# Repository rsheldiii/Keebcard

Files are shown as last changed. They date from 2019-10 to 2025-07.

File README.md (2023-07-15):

# The KeebCard, an open-source, low-power, mechanical switch computer keychain

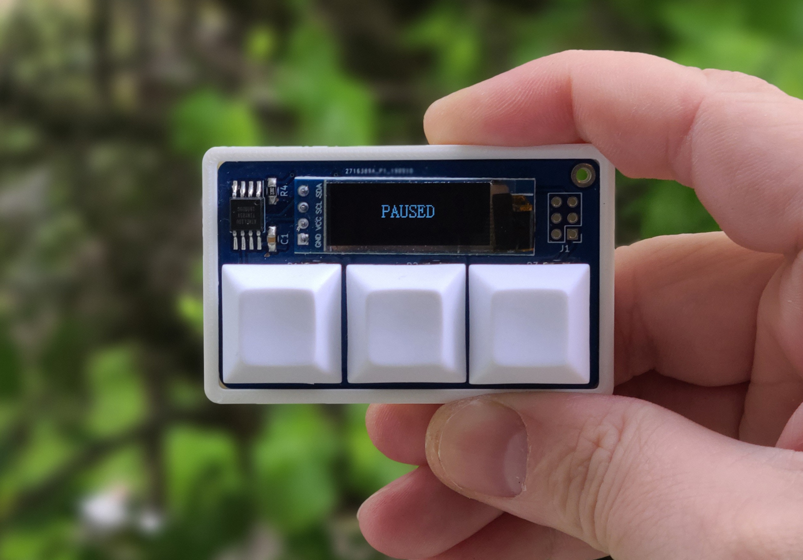
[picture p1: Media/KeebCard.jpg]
Prototype KeebCard picture


This is the home of the KeebCard project. Originally designed as a business card, people loved it so much I decided to release a version of it as open-source (TODO: add a license).

The KeebCard is centered around an SSD1306-powered 128x32 monochromatic display and an ATTINY85-10SU. The code uses the wonderful [Tiny4kOLED library](https://github.com/datacute/Tiny4kOLED) to communicate with the screen via i2c. With 8 kilobytes of program space and 512 bytes of RAM, it's a fun challenge getting anything to run on this thing!

# OpenSaucers

OpenSauce attendees, thanks for supporting TheKeebProject! Check out the DIY assembly video below. The amount of components present in the bag indicates what they are; there is one capacitor, two i2c resistors (on the back) and four pull-up resistors. The assembly video should go over everything, if you have any trouble get in touch!

## DIY Assembly

[Head here for the current DIY assembly video](https://www.youtube.com/watch?v=mJQla--lSXY).

## Case Assembly (Button and LowPro)

Watch [this quick video](https://www.youtube.com/watch?v=yVERQCmgONw) if you want to know how to use the cases! Especially important for button cases, they can be tricky

# Flashing/Code

At the base of this project (currently) is the code that runs on the machine, you can `git clone` or download zip and open the KeebCard.ino file in Arduino. I don't normally program in C++, so it's a little rough. You can change what program is flashed by changing the define at the top of KeebCard.ino.

The KeebCard code is currently compiled and flashed with an ISP programmer via the Arduino suite. [check out the flashing tutorial here](https://www.youtube.com/watch?v=2kj1aFIwNek)

### A note about dependencies

Currently, all dependencies can be installed via the Arduino library manager, check out the flashing tutorial.

There used to be a dependency on the [Arduino Entropy Library](https://github.com/pmjdebruijn/Arduino-Entropy-Library) that needed to be downloaded separately, but it was causing memory errors due to how the Arduino suite includes files. I'll be breaking programs out into separate folders eventually, after which we'll reinstate the entropy library.

# Flashing your own programs

I made a guide on how Conway's Game of Life works on the KeebCard, which will hopefully help you write your own programs! you can check that out [here](https://www.youtube.com/watch?v=X3y9NNHXf2Y)

# Troubleshooting

Having successfully hand-soldered >30 of these now, I put the two most common problems people encounter in [this video](https://www.youtube.com/watch?v=W7IxT4Zf5qs). If you're having issues take a look!

# Fabbing

If you want to make your own run of KeebCard boards, check out the GERBERS directory. These are gerbers produced by the standard settings in Kicad. They are confirmed to work with JLCPCB, but probably work just fine at a bunch of other board shops.

## BOM

All parts are available from Mouser save the screen

* 1x [SMTU2032-LF](https://www.mouser.com/ProductDetail/614-SMTU2032-LF)
* 1x [0805 0.1uF capacitor](https://www.mouser.com/ProductDetail/710-885012207016)
* 4x [0805 22kOhm resistors](https://www.mouser.com/ProductDetail/603-RC0805FR-0722KL)
* 2x [0805 4.7 kOhm resistors](https://www.mouser.com/ProductDetail/603-RC0805FR-074K7L)
* 1x [ATTINY85V-10SU](https://www.mouser.com/ProductDetail/556-ATTINY85V10SU)
* [Some headers](https://www.mouser.com/ProductDetail/538-22-28-4012)
* 1x [screen](https://www.aliexpress.com/item/32712441521.html?spm=a2g0s.9042311.0.0.296f4c4dcIoeUh)
* 3x [cherry MX](https://www.mouser.com/ProductDetail/CHERRY/MX1A-E1NW) or Kailh Choc switches and keycaps

# Modifying

If you want to modify the design, check out the KeebCard directory, which houses the original Kicad project.  

# KeebCard in media

If you've seen the KeebCard elsewhere, please let me know!

* Unilad Tech: https://www.facebook.com/UNILADTech/videos/1574779679325114/?v=1574779679325114
* AlexGyver's Youtube channel: https://www.youtube.com/watch?v=djgHV5JCNTk

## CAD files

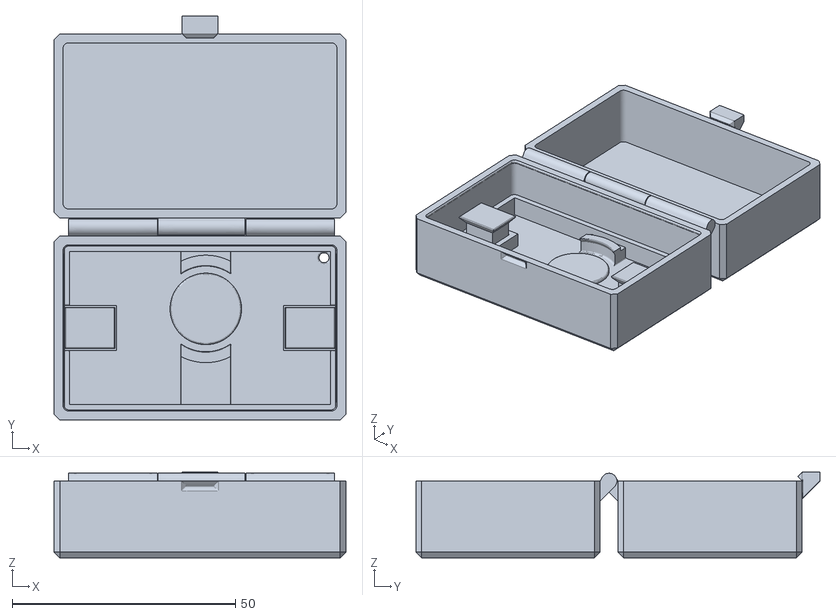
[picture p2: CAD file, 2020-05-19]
Cases/KeebCard Battery Case v18.stl
65.3 x 90.4 x 19.2

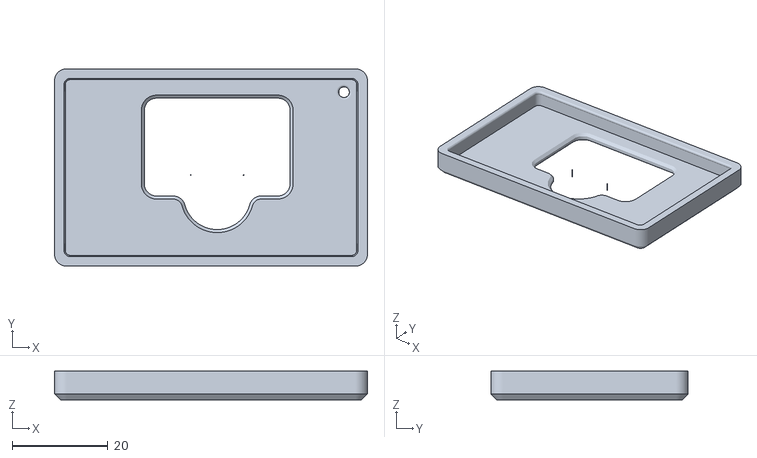
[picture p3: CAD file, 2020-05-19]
Cases/KeebCard LowPro Case v2.stl
65.3 x 41.2 x 6.05

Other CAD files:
Cases/KeebCard Battery Case v18.f3d
Cases/KeebCard LowPro Case v3.f3d

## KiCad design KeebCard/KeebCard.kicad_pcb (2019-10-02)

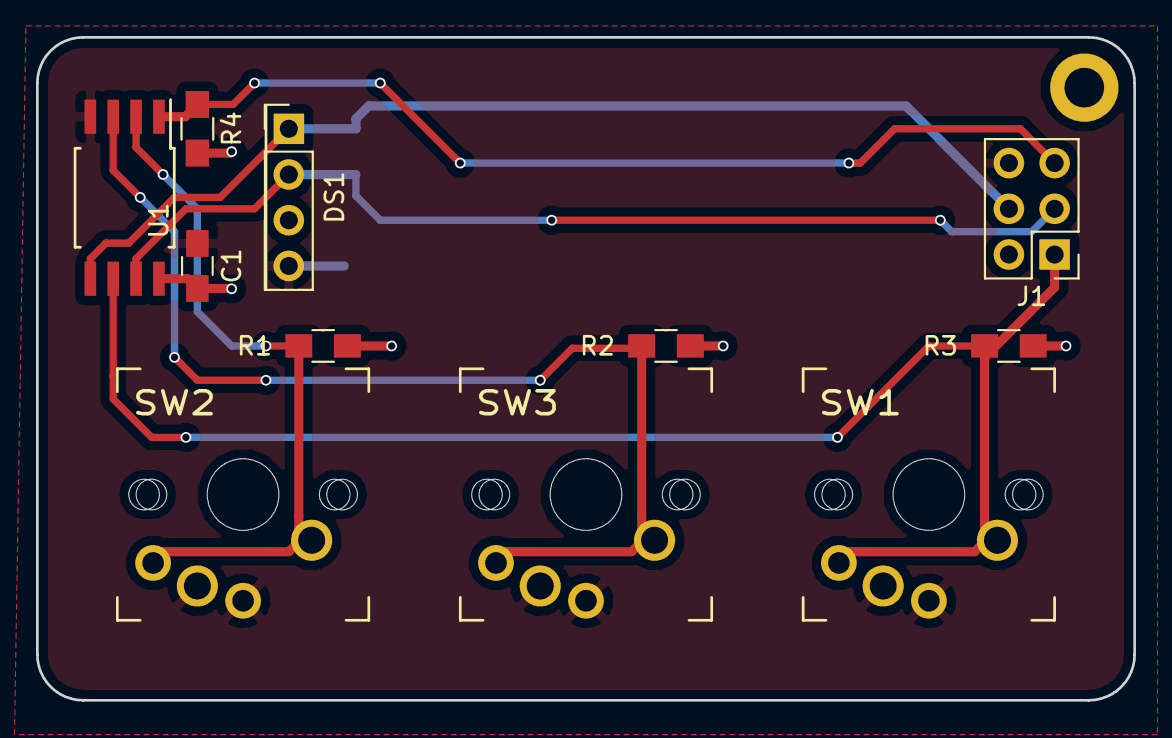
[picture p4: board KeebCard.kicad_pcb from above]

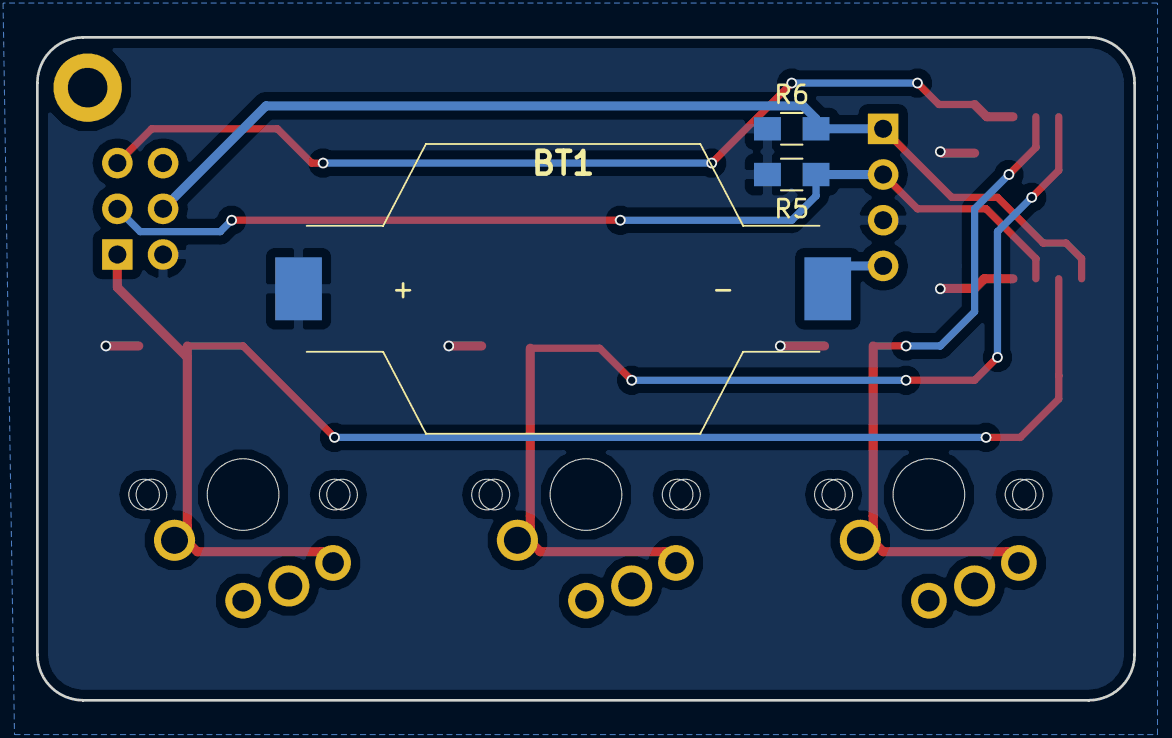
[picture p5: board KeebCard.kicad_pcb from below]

Board: 2 copper layers, 61.0 x 36.8 mm, 14 parts (3 on the bottom side), 8 nets.

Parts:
BT1: CR2032; SMTU2032
C1: 100nF; C_0805_HandSoldering
DS1: SSD1306-128x32; SSD1306_OLED_Display_128x32
J1: Conn_02x03_Odd_Even; Pin_Header_Straight_2x03_Pitch2.54mm
R1, R2, R3, R4: 22K; R_0805_HandSoldering
R5, R6: 4.7k; R_0805_HandSoldering
SW1, SW2, SW3: SW_Push; CHERRY_CHOC_PCB
U1: ATTINY85-20SU

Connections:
/PB0: DS1.4, J1.4, R6.1, U1.5
/PB1: J1.1, R3.2, SW1.2, U1.6
/PB2: DS1.3, J1.3, R5.1, U1.7
/PB3: R1.2, SW2.2, U1.2
/PB4: R2.2, SW3.2, U1.3
/PB5: J1.5, R4.1, U1.1
GND: BT1.2, C1.2, DS1.1, J1.6, SW1.1, SW2.1, SW3.1, U1.4
VCC: BT1.1, C1.1, DS1.2, J1.2, R1.1, R2.1, R3.1, R4.2, R5.2, R6.2, U1.8

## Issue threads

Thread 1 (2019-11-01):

Some Kicad library are missing

BenRoe, 2019-11-01:
I will add a on/off switch to the pcb.
Problem is that some symbol libraries are missing (bobness_card.lib and KeebCard.lib).
Also the footprints are in six different libraries. Can you move the parts in one symbol and one footprint library?
Or please zip all libraries and upload it. I can merge if you wan't.
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

rsheldiii, 2020-01-22:
Whoops, totally missed this, sorry about that.

None of those libraries are used, so they are safe to ignore. I've removed them from the library tables so this should be all set.

thanks for pointing this out!

Closed 2020-01-22.

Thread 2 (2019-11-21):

Oled flashing pausing continuously

0xhjohnson, 2019-11-21:
Just finished soldering the device up and it is continuously alternating between paused and then plays a frame. Any ideas where to start troubleshooting?

rsheldiii, 2019-11-21:
The screen pausing continuously indicates the voltage on the middle button's GPIO is low - most likely there's a bridge somewhere to ground or another pin. The most common place for that is the microcontroller, so I'd check to make sure there aren't any bridges there. The middle button pin is PB4, which is the second pin from the left on the topmost row of pins when it's on the board. The pin to the left is ground, so any solder bridge to that pin would definitely do it.

Let me know if that's the culprit!

0xhjohnson, 2019-11-22:
Thanks for your help. I will investigate and report back.

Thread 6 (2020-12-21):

Conflicting declaration

MyNameIs-Nigel, 2020-12-21:
Hey! I was following your flashing tutorial on YouTube and found an issue that I am having. I can not compile the code because of an exit. "conflicting declaration 'typedef struct UPosition UPosition'"

How do you think I could go about resolving this issue? Here are the steps I followed to ensure you can run into this error:

1. Download the code from the github
2. Download arduino, rename the keebcard-master to keebcard
3. Open Keebcard.ino
4. Add TinyWireM.h and Tiny4kOLED.h libraries
5. Comment `#define TETRIS` and uncomment `#define PONG`
Compile the code.

These are the exact steps shown in the video (to my memory) and resulted in the following error: (Info and such included in the error message)

```
Arduino: 1.8.9 (Windows 10), Board: "ATtiny25/45/85, ATtiny85, Internal 1 MHz"

In file included from C:\Users\Nigel\Desktop\keebcard\Keebcard.ino:21:0:

Tetris.h:13:3: error: conflicting declaration 'typedef struct Position Position'

 } Position;

   ^

In file included from C:\Users\Nigel\Desktop\keebcard\Conway.cpp:2:0:

sketch\Conway.h:12:3: note: previous declaration as 'typedef struct Position Position'

 } Position;

   ^

exit status 1
conflicting declaration 'typedef struct Position Position'

This report would have more information with
"Show verbose output during compilation"
option enabled in File -> Preferences.
```

MyNameIs-Nigel, 2020-12-21:
Heyy! I just noticed I posted the Wrong error code! My bad!! Still, similar enough error. This error occurs on every one I have found.

Here is the updated error.

```
Arduino: 1.8.9 (Windows 10), Board: "ATtiny25/45/85, ATtiny85, Internal 1 MHz"

In file included from C:\Users\Nigel\Desktop\keebcard\Keebcard.ino:25:0:

Pong.h:7:3: error: conflicting declaration 'typedef struct UPosition UPosition'

 } UPosition;

   ^

In file included from C:\Users\Nigel\Desktop\keebcard\Conway.cpp:2:0:

sketch\Conway.h:7:3: note: previous declaration as 'typedef struct UPosition UPosition'

 } UPosition;

   ^

In file included from C:\Users\Nigel\Desktop\keebcard\Keebcard.ino:25:0:

Pong.h:12:3: error: conflicting declaration 'typedef struct Position Position'

 } Position;

   ^

In file included from C:\Users\Nigel\Desktop\keebcard\Conway.cpp:2:0:

sketch\Conway.h:12:3: note: previous declaration as 'typedef struct Position Position'

 } Position;

   ^

exit status 1
conflicting declaration 'typedef struct UPosition UPosition'

This report would have more information with
"Show verbose output during compilation"
option enabled in File -> Preferences.

```

MyNameIs-Nigel, 2020-12-21:
Hey there! I deleted everything except the necessary files and pong. So this leaves `Keebcard`, `Pong.cpp`, `Pong.h`, and `settings.h`.

Now it will compile.

Still not sure, is this a necessary step? As to my knowledge, you do not include this step in your video..

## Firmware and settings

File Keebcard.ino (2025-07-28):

#include <TinyWireM.h>
#include <Tiny4kOLED.h>
#include <avr/wdt.h>
// #include <Entropy.h>
#include "settings.h"


// PROGRAM DEFINES =============================================================

// uncomment whichever one you want
// #define BUSINESS_CARD
#define TETRIS
// #define CONWAY
// #define PONG
// #define SNAKE

// cut down on features since digispark has a big bootloader
// #define DIGISPARK


#ifdef TETRIS
#include "Tetris.h"
#elif defined(CONWAY)
#include "Conway.h"
#elif defined(PONG)
#include "Pong.h"
#elif defined(BUSINESS_CARD)
#include "BusinessCard.h"
#elif defined(SNAKE)
#include "Snake.h"
#endif

void universal_setup() {

  // flip screen horizontally
  // oled.setSegmentRemap(0xA0);
  // flip screen vertically
  // oled.setComOutputDirection(0xC0);

  oled.begin();

  oled.setFont(FONT8X16);
  // Switch the half of RAM that we are writing to, to be the half that is non currently displayed
  oled.switchRenderFrame();

  // clear both buffers of any dead squirrels
  oled.clear();
  oled.switchFrame();
  oled.clear();

  // Turn on the display
  oled.on();

  // seed random number with value from the analog pin
  // it doesn't vary all that much, but it helps
  // srand(analogRead(MIDDLE_BUTTON) + analogRead(2) + analogRead(3));
  // here's the good stuff, Entropy based off clock jitter
//  Entropy.initialize();

  pinMode(LEFT_BUTTON, INPUT);
  pinMode(RIGHT_BUTTON, INPUT);
  pinMode(MIDDLE_BUTTON, INPUT);

#ifdef SNAKE
  oled.setMemoryAddressingMode(0); // TODO prolly don't need this
  // no double buffering for now. very little to update so it runs fast anyways
  oled.switchRenderFrame();
#endif
}

void wdt_check_reset() {
  MCUSR &= ~(1 << WDRF);  // Clear watchdog reset flag
  wdt_disable();          // Disable watchdog on startup
}


void setup() {
  wdt_check_reset(); // Disable watchdog timer on startup
  universal_setup();
  setup_game();
}

void setup_game() {
#ifdef TETRIS
  GIMSK = 0b00100000;    // turns on pin change interrupts
  PCMSK = 0b00011010;    // turn on interrupts on pins PB0, PB1, &amp;amp; PB4
  sei();                 // enables interrupts

  Tetris tetris(&oled);
  gameOver(tetris.run());
  oled.switchFrame();
#elif defined(CONWAY)
  oled.setMemoryAddressingMode(0); // TODO prolly don't need this
  Conway conway(&oled);
  conway.run();
#elif defined(BUSINESS_CARD)
  businessCard(&oled);
#elif defined(PONG)
  oled.setCursor(8, 1);
  oled.print(F("PLAYER 1 START"));
  oled.switchFrame();
  delay(800);
  oled.switchFrame();
  oled.clear();
  oled.setMemoryAddressingMode(1);
  Pong pong(&oled);
  pong.run();
#elif defined(SNAKE)
  oled.setCursor(8, 1);
  oled.print(F("NOKIA OS"));
  // oled.switchFrame();
  delay(800);
  // oled.switchFrame();
  oled.clear();
  Snake snake(&oled);
  gameOver(snake.run());
#endif
}

void loop() {
  if (digitalRead(MIDDLE_BUTTON) == LOW) {
    // oled.clear();
    // oled.switchFrame();
    // oled.clear();
    // setup_game();
  }
}

void gameOver(uint32_t score) {
  oled.clear();
  oled.setCursor(0, 0);
  oled.print(F("Game Over!"));
  oled.setCursor(0, 2);
  oled.print(F("Score: "));
  oled.print(score);
  oled.switchFrame();

  delay(100);
  
  // Wait for middle button press to restart
  while (true) {
    if (digitalRead(MIDDLE_BUTTON) == LOW) {
      // Wait for button release to avoid immediate re-trigger
      while (digitalRead(MIDDLE_BUTTON) == LOW) {
          delay(10);
      }

      oled.clear();
      oled.setCursor(0,0);
      oled.print(F("Restarting..."));
      oled.switchFrame();

      delay(100);
      // Enable watchdog timer and reset system
      wdt_enable(WDTO_250MS);
      while(1); // Wait for watchdog reset
    }
    delay(10); // Small delay to prevent excessive CPU usage
  }
}

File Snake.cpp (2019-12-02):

#include "settings.h"
#include "Snake.h"


const uint8_t BOARD_WIDTH = 48;
const uint8_t BOARD_HEIGHT = 16;
const uint8_t STARTING_SCORE = 4;

// the board is not a multiple of the screen height, so this is the difference
// from one edge of the screen to the board
const uint8_t HORIZONTAL_GAP = ((64 - BOARD_WIDTH) / 2);

// if you're reading this and it's still broken out it's for testing purposes
// each byte represents a 16x2 swath of pixels, which is then of course 8 positions 2x2.
// swaths start in the top left and proceed rightwards in rows
// pixels start at the top as well and go downwards
// 8 for uint8_t
const uint8_t BOARD_SIZE = BOARD_WIDTH * BOARD_HEIGHT / 8;


// divided by 4 because quadruple direction
static QuadrupleDirection SnakePath::snakePath[BOARD_WIDTH * BOARD_HEIGHT / 4] = { { RIGHT, RIGHT, RIGHT, RIGHT }, { RIGHT, RIGHT, RIGHT, RIGHT }, { RIGHT, RIGHT, RIGHT, RIGHT } }; // TODO NEEDS TO BE 256(ish) but memory instability

Direction SnakePath::get(uint16_t index) {
  QuadrupleDirection d = snakePath[index >> 2];
  switch((uint8_t)(index & 0b11)) {
    case 0:
      return d.firstDirection;
    case 1:
      return d.secondDirection;
    case 2:
      return d.thirdDirection;
    case 3:
      return d.fourthDirection;
  }
}

void SnakePath::set(uint16_t index, Direction direction) {
  switch((uint8_t)(index & 0b11)) {
    case 0:
      snakePath[index >> 2].firstDirection = direction;
      break;
    case 1:
      snakePath[index >> 2].secondDirection = direction;
      break;
    case 2:
      snakePath[index >> 2].thirdDirection = direction;
      break;
    case 3:
      snakePath[index >> 2].fourthDirection = direction;
      break;
  }
}

static uint8_t Snake::board[BOARD_SIZE] = { 0 };

static Position Snake::tailPosition = {1, 7};
static Position Snake::headPosition = {1 + STARTING_SCORE + 1, 7};
static Position Snake::foodPosition = {32, 7};

static Direction Snake::direction = RIGHT;
static Direction Snake::lastDirection = RIGHT;

static uint16_t Snake::score = STARTING_SCORE;
static bool Snake::gameOver = false;
static bool Snake::scoredThisTurn = false;
static uint8_t Snake::time;
static uint8_t Snake::debounce = 0;
static uint8_t Snake::linksToAdd = 0;

// snakePath defines the association between snake links. Snake links can only be the cardinal neighbor of their next-of-kin, so we only need 4 bits to represent this

Snake::Snake(SSD1306Device* _oled) {
  oled = _oled;
  oled->fill(0);
}

// set up the play area. used at start and for pause
void Snake::setup() {
  oled->setMemoryAddressingMode(1);
  // * 2 because we are rasterized - every pixel is a 2x2 squares
  oled->setCursor((HORIZONTAL_GAP - 1) * 2,0);
  oled->startData();
  for(uint8_t j = 0; j < 8; j++){
    oled->sendData(0xffff);
  }

  oled->endData();
  oled->setCursor((BOARD_WIDTH + HORIZONTAL_GAP) * 2, 0);
  for(uint8_t i = 0; i < 8; i++) {
    oled->sendData(0xffff);
  }
  oled->endData();
  oled->setMemoryAddressingMode(0);

  Position position = tailPosition;

  // "initialize" snake onto screen
  sendToGrid(position, true);
  for (uint8_t i = 0; i < score; i++) {
    Direction d = snakePath.get(i);
    addDeltaToPosition(position, d);
    sendToGrid(position, true);
  }
  sendToGrid(headPosition, true);
}

uint16_t Snake::run() {
  setup();

  setNewFoodPosition();

  while(!gameOver) {
    checkForPause();
    // we don't have to but, just in case...
    sendToGrid(foodPosition, true);

    time = millis();

    checkForScore();
    checkInputs();

    moveSnake();
    // cache last direction to use it when moving the head later
    // for a brief moment direction and lastDirection are both the same direction,
    // but we correct immediately.
    // this isn't done in checkInputs as we call that multiple times
    lastDirection = direction;

    // better than a no op
    while ((uint8_t)(millis() - time) < 120) { // 160
      checkInputs();
    }

    checkGameOver();

    // for debugging food placement
    // oled->setCursor(0,0);
    // oled->print(foodPosition.x);

    // delay(max(120 - (millis() - time), 0));
    // this is for debugging
    // renderScreen();
  }
  return score - 4;
}

void Snake::checkInputs() {
  // TODO if you're really lucky millis() will wrap to 0 and this doesn't work. 1/256 of the time
  // lol I could just check when I set it I guess
  // but it works for now
  if (debounce !=0) {
    if (uint8_t(millis() - debounce) < 150) {
      return;
    } else {
      debounce = 0;
    }
  }

  if (digitalRead(LEFT_BUTTON) == LOW) {
    // not milliseconds, invocations of checkInputs
    debounce = millis();
    if (lastDirection == LEFT) {
      direction = DOWN;
    } else {
      direction = (uint8_t)lastDirection-1;
    }
  }

  if (digitalRead(RIGHT_BUTTON) == LOW) {
    debounce = millis();
    // direction is in order - left up right down - so add 1 and % 4 and poof it works
    direction = (lastDirection+1) & 3;
  }
}

void Snake::moveSnake() {
  sendToGrid(tailPosition, false);
  // placed first so we can use the old head position
  updateTailPosition();

  // we don't have to sendToGrid(tailPosition, true) since there should always already be a pixel at the new tail position. it's great for testing though
  sendToGrid(tailPosition, true);

  updateHeadPosition();

  sendToGrid(headPosition, true);
}


// must be called _before_ head moves
void Snake::updateTailPosition() {
  // tail doesn't move the turn we score
  if (linksToAdd > 0) {
    return;
  }
  // no links if score is 0
  if (score == 0) {
    tailPosition = {headPosition.x, headPosition.y}; // TODO should be able to just do headPosition. shallow copy but no pointers so meh
  } else {
    // get last link in the chain
    Direction linkBeforeTail = snakePath.get(0);
    // move tailPosition to last link in the chain
    // we will eventually break apart the uint8_t to two uint4_t and cast to a Direction
    // these numbers might not match up then
    addDeltaToPosition(tailPosition, linkBeforeTail);
  }
}

void Snake::updateHeadPosition() {
  if ((score > 0) || linksToAdd > 0) {
    // push previous direction of head onto snakePath
    snakePath.set(score, lastDirection);

    // shrink path by 1 if not scored
    if (linksToAdd == 0) {
      for (uint16_t i = 0; i < score; i++) {
        snakePath.set(i, snakePath.get(i+1));
      }
    } else {
      // do it now so snakePath[score] isn't wrong
      linksToAdd--;
      score++;
      if (scoredThisTurn){
        setNewFoodPosition();
      }
    }
  }
  // move head according to that direction
  addDeltaToPosition(headPosition, direction);
}
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

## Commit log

2019-08-02 Add current code as-is
2019-08-03 Rename so arduino doesn't complain
    [Keebcard.ino]
2019-08-03 Make compiler happy again
    previously upgraded to a newer version of tiny4koled that doesn't like tiny4koled.h to be included, else there are multiple declaration problems. switched to a pointer and tiny4koled_common.h and it goes away
    [Pong.cpp]
2019-08-19 Update gitignore for Kicad files
2019-08-19 Add Kicad project
    [KeebCard.kicad_pcb, KeebCard.sch]
2019-08-19 Add Gerbers
    [KeebCard-B.Cu.gbr, KeebCard-B.Mask.gbr, KeebCard-B.SilkS.gbr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]
2019-10-02 Last minute PCB changes
    [KeebCard.kicad_pcb]
2019-10-02 revert weird changes
    some weird state accidentally got committed. Should really switch to linux with this
    [Keebcard.ino]
2019-10-08 Fix setNewFoodPosition
    we were randomly picking points and checking if they collide which was not gonna scale at all. We still try to do that, but now if we fail we scan for segments with open pixels, randomly pick one, and use that instead.
    [Keebcard.ino, Pong.cpp, Snake.cpp]
2019-10-11 last tweaks I swear
    reinstitute easier english shots, correct early AI return, add minimal randomness to serve. swap buttons
    [Keebcard.ino, Pong.cpp]
2019-10-19 Snake updates
    trying to allow for rerunning the program, accounting for memory limits with a smaller board
2019-10-23 add provisional assembly video
    I want to reshoot it, I ramble a lot
2019-10-28 Edge case cleanup
    Pretty sure this is going to be the production version unless I find anything wrong about it tomorrow. fix a lot of bounding edge cases and revamp fallback food placement logic because it was dead wrong.
    [Keebcard.ino, Snake.cpp]
2019-12-02 Fix corruption on game over (I think)
    every once in a while Snake corrupts when the snake collides with the upper wall. I think the y coordinate is wrapping past zero and accessing memory it shouldn't, and I think this fixes it
    [Snake.cpp]
2019-12-02 Tetris updates
    found my old code, implemented auto-down, removed "ticks per frame" concept from event loop, added rotation "kicking" where the piece will move 1 spot to the left or right if it allows a rotation tha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
2019-12-03 bash my way through a pin interrupt input system. fix some bugs on the way
    [Keebcard.ino]
2019-12-08 sundries. speed things up a bit. debounce buttons. always rotate
2020-01-22 fix bad kicad lib declarations
    [KeebCard.sch]
2020-01-22 fix up footprint libraries too
2020-04-12 Fix Conway
    RIP. Switches board to big-endian and fixes a few issues - like incorrectly using UPosition for negative deltas in the neighbor function and < vs <= mishap
2020-05-19 Add cases
    [KeebCard Battery Case v18.f3d, KeebCard Battery Case v18.stl, KeebCard LowPro Case v2.stl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]
2020-05-26 Add case video link
2020-05-26 Spring cleaning in README.md
2024-01-06 finally forever-more fix Tetris buttons
    [Keebcard.ino]
